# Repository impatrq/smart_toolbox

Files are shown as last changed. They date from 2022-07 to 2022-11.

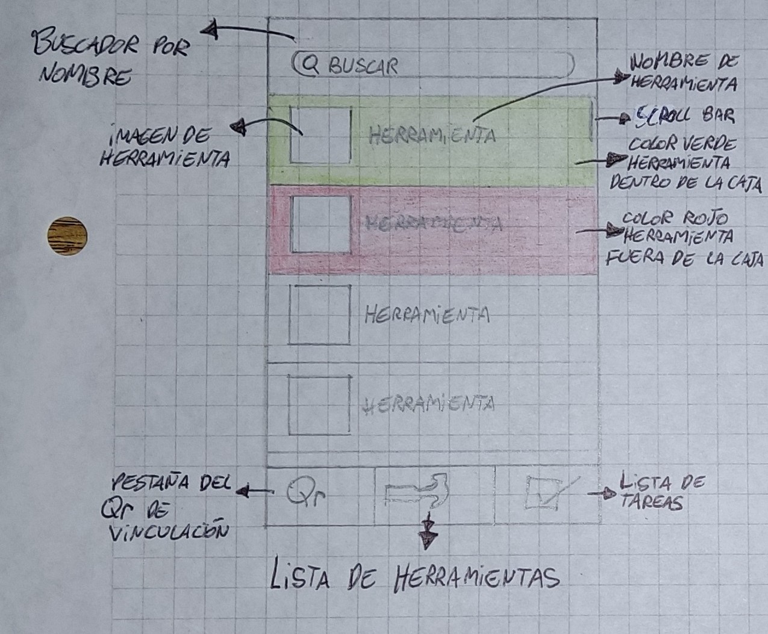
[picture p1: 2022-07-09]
documentacion/diseño-aplicacion-movil/IMG_20220708_201354_3.jpg

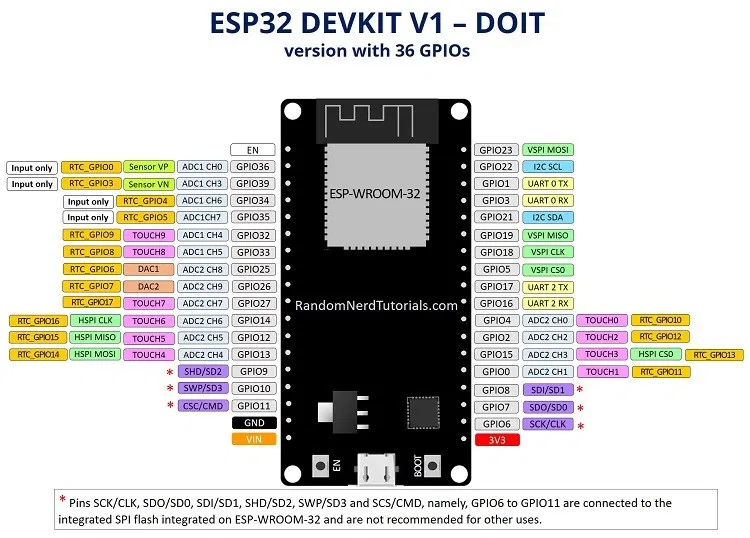
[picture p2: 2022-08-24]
datasheets/ESP32-Pinout.webp

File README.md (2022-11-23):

<div align="center">

# [Smart Toolbox](https://smart-toolbox.vercel.app/)



&nbsp;

| Página web | Email | Instagram |
|---|---|---|
|[smart-toolbox.vercel.app](https://smart-toolbox.vercel.app/)|smart.toolbox@proton.me|[@smart.toolbox.2022](https://www.instagram.com/smart.toolbox.2022)|

&nbsp;

</div>

## ¿Qué es Smart Toolbox?

Smart Toolbox aborda la problemática de los _errores humanos_ en los entornos de trabajo con _herramientas_, que pueden producir _accidentes_ y/o _costos_ adicionales. Con la ayuda de diversas tecnologías creamos un sistema que permite tener un mayor control sobre las herramientas en un taller, reduciendo así el _riesgo de un siniestro_.

## ¿De dónde surgió la idea?

Este proyecto surgió como una variación de otro llamado _Tool Finder_. La principal función de este era la de encontrar, mediante un localizador, las herramientas de trabajo en el taller. A medida que ibamos progresando en el Tool Finder, se fueron descartando y transformando ideas, pero el objetivo de prevenir accidentes nunca cambió. Así surgió _Smart Toolbox_.

## ¿Cómo funciona?

Durante la jornada de trabajo, el operario _dispondrá de todas las tareas a realizar en el día en la aplicación móvil_. Estas serán cargadas a través de una página web.
Después de terminar la jornada de trabajo, el operario deberá guardar todas las herramientas en la caja y, de este modo, evitar el extravío de éstas. En el caso contrario, al cerrarse alguno de los cajones, el sistema _detectará que faltan herramientas_, avisándole de esto mediante un sonido. Los utensilios faltantes se podrán _visualizar en una aplicacion móvil_ vinculada a la caja y en una _interfaz gráfica_.

## Tecnologías utilizadas

### Aplicación móvil

- Ionic con React
- Typescript
- Bootstrap

### Interfaz gráfica

- Electron
- React
- Typescript
- Bootstrap

### Esquemáticos

- KiCad

### Página web

- Next.js
- Typescript
- TailwindCSS
- Bootstrap

### Base de datos

- Firebase Realtime Database

### Microcontrolador

- uPython

### Planos

- AutoCAD

## ¿Quiénes somos?

Somos un grupo de alumnos de E.E.S.T. N°7 "Taller Regional Quilmes" (IMPA).

### Esquivel, Agustín

--> 📧 esquivel.agustin04@gmail.com

### Herrera, Lucas

--> 📧 lucassherreraa2003@gmail.com

### Mariani, Ramiro

--> 📧 ramiromariani99@gmail.com

### Martínez Joaquín

--> 📧 joaquinosmartinez@gmail.com

### Torres, Federico

--> 📧 federicotorres233@protonmail.com

### Vanore, Miqueas

--> 📧 vnmiqueas@gmail.com

<div align="center">



</div>

## Logros

<div align="center">

### 🥇 Primer puesto en Prototipos II 🥇



</div>

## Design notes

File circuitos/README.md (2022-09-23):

# Circuitos
Esta carpeta contiene los archivos de los esquemáticos y las placas de circuito impreso.

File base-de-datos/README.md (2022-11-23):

# Base de datos
Esta carpeta contiene el esquema noSQL que debe ser importado en una base de datos Realtime Database en Firebase y un ejemplo.

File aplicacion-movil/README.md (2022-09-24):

# Aplicación móvil
Esta carpeta contiene el código fuente de la aplicación que le permite al trabajador tener control sobre las herramientas de una caja y de sus tareas a realizar en el día.

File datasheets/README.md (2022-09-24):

# Datasheets
Esta carpeta contiene las hojas de datos de los componentes de Smart Toolbox.

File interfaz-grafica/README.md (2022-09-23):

# Interfaz gráfica
Esta carpeta contiene el código fuente de la aplicación que le permite al encargado del sector tener control total sobre las cajas y sus operarios

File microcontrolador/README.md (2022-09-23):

# Microcontrolador
Esta carpeta contiene el código fuente del microcontrolador dentro de cada caja, que envía infromación sobre su estado y sus herramientas faltantes.

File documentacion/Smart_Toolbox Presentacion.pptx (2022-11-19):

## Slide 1

Integrantes:

- Esquivel, Agustín Lautaro
- Herrera, Lucas Leandro
- Martínez, Joaquín Sebastián
- Mariani, Ramiro Uriel
- Torres, Federico Iván
- Vanore, Miqueas Juan Bautista

## Smart Toolbox

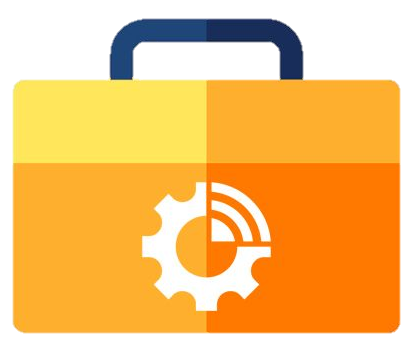
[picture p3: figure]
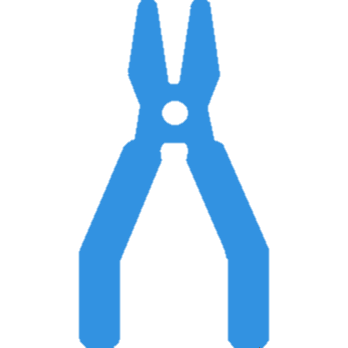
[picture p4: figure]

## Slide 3

¿Cómo funciona?

En la aplicación móvil se mostrarán dichas herramientas.

En la interfaz gráfica se pueden visualizar y administrar cada Smart Toolbox.

Si hay herramientas faltantes, suena una alarma al cerrar todos los cajones.

- Mediante un complejo sistema, advierte al operario si hay alguna herramienta faltante.

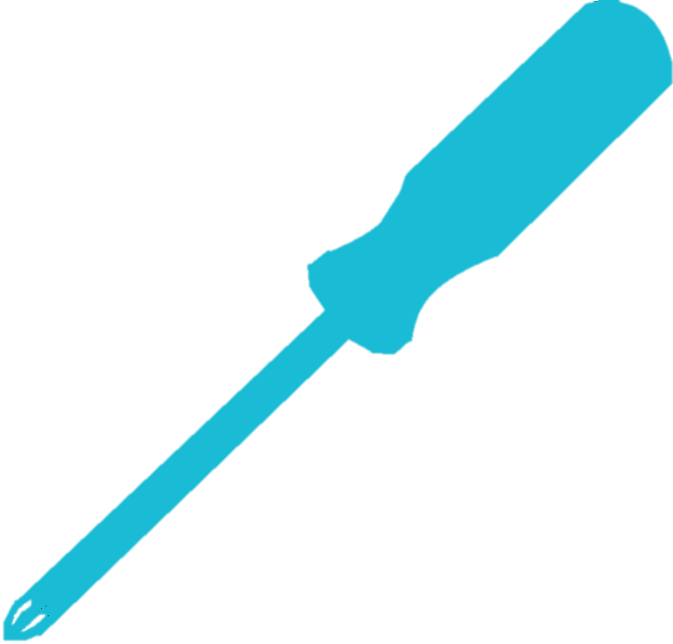
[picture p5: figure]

## El microcontrolador

Envía el estado de cada herramienta a la base de datos

## Cada herramienta:

🔨

- Está asociada a un sensor (para saber si se encuentra, o no, en su lugar)

- Está cargada en una base de datos.

## Los contactos magnéticos

Detectan si los cajones están abiertos o cerrados

## ¿A quién está orientada?

- Empresas
- Talleres mecánicos
- Tripulación y pasajeros del avión
- Operarios especializados en Aeronáutica (MMA) y Aviónica (MERA)

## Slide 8

🔨

¡Grandes beneficios!

Previene pérdidas de dinero millonarias.

Mayor seguridad para la tripulación y pasajeros.

La eficiencia del operario es mejorada.

Se reduce el riesgo de accidentes por olvido de herramientas.

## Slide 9

Cada operario tiene su Smart Toolbox y tiene que registrarse al comienzo del día

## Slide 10

Aplicación móvil

- Permite vincular el usuario con la Smart Toolbox mediante un QR.

- Muestra las tareas a realizar en el día.

- Muestra las herramientas faltantes de la caja.

- Permite vincular el usuario con la Smart Toolbox mediante un QR.

- Muestra las herramientas faltantes de la caja.

- Muestra las tareas a realizar en el día.

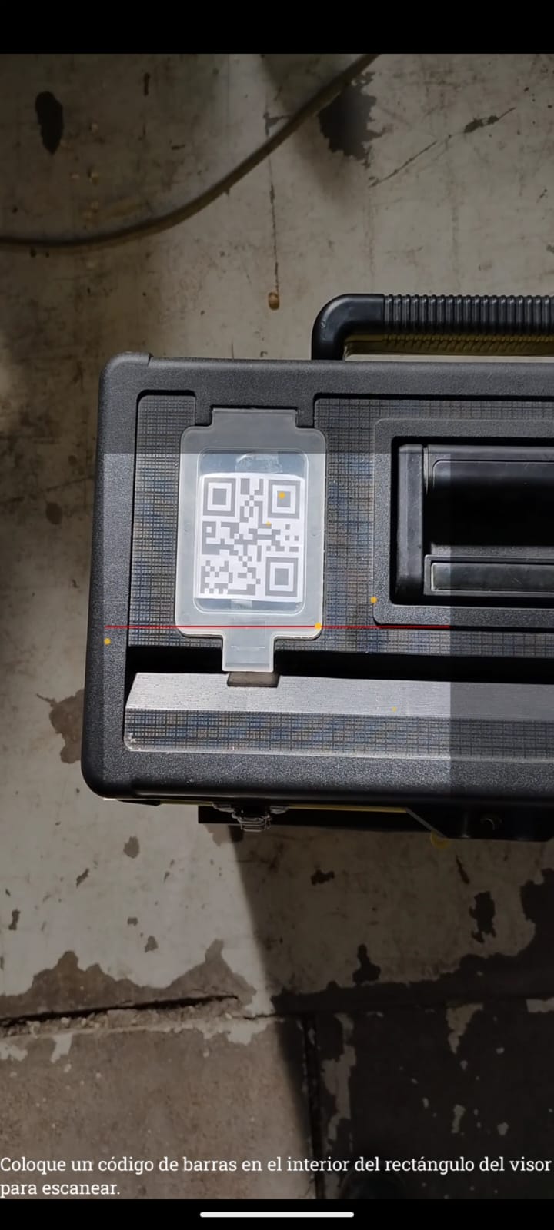
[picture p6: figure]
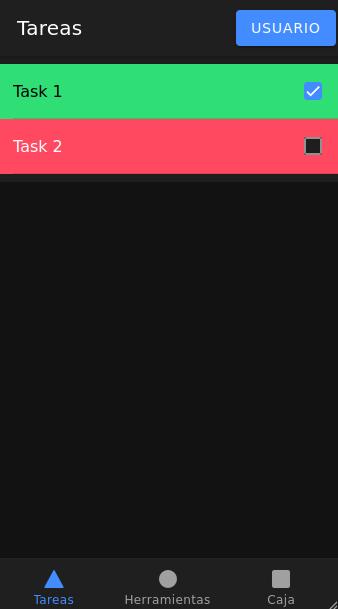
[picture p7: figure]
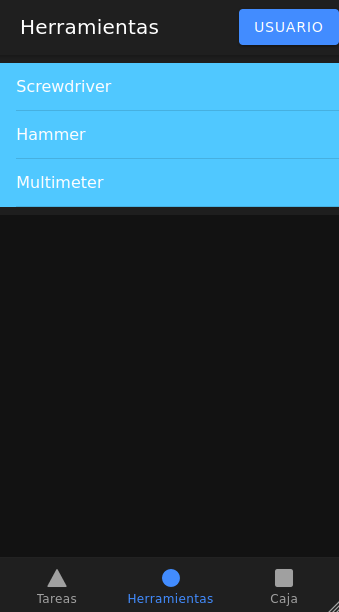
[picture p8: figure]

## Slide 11

Interfaz gráfica

Es una aplicación de escritorio, donde el encargado puede:

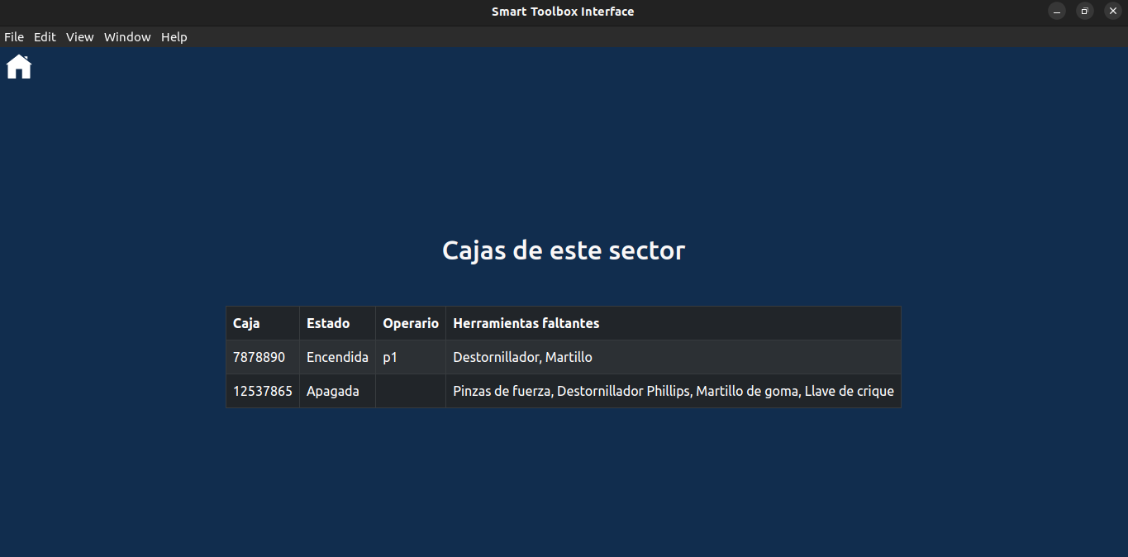
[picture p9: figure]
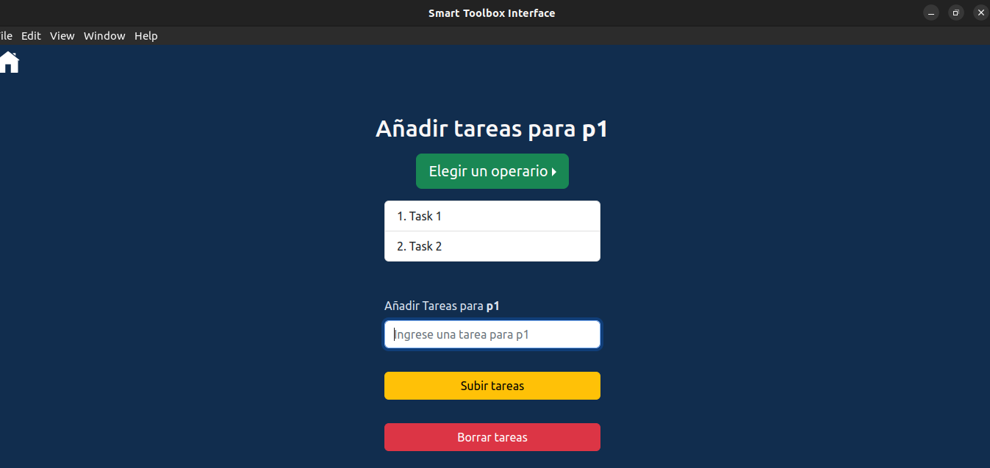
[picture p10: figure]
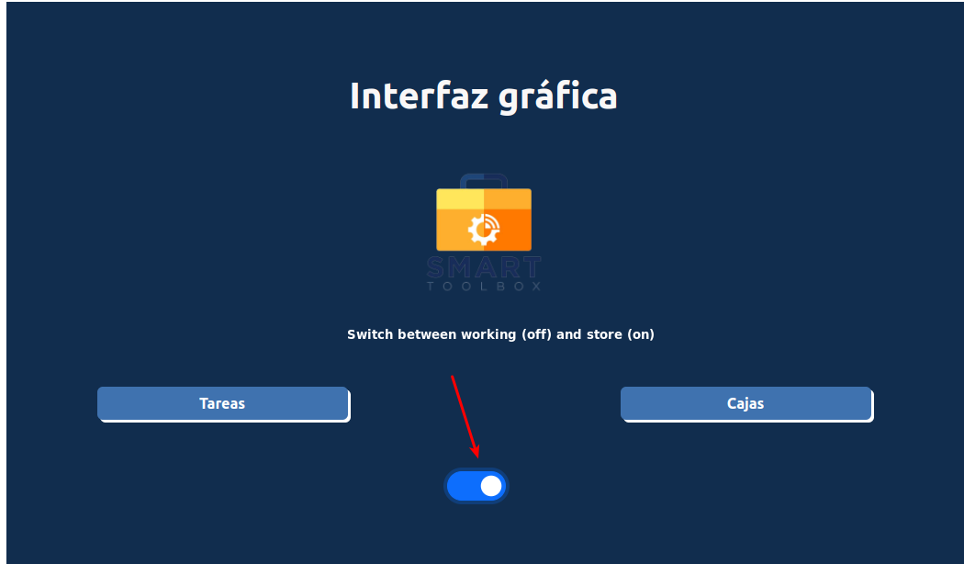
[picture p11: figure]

Ver la información sobre cada Smart Toolbox y a quién está vinculada.

Cargar, en la base de datos, las tareas para hacer en el día por cada operario.

Ver si hay herramientas faltantes.

Determinar el horario de regreso de las Smart Toolbox.

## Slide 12

Smart
Toolbox

Seguridad, Orden y Eficiencia

## Visitanos en:

smart-toolbox.tk

Seguinos en Instagram

@smart.toolbox.2022

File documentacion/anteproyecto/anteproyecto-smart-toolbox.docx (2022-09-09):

Smart Toolbox

Presentación de anteproyecto

Título del proyecto:

El nombre “Smart Toolbox”, es fácil de recordar ya que permite representar de manera rápida en la mente de que trata el proyecto.

Integrantes:

- MARIANI, Ramiro Uriel
- TORRES, Federico Iván
- HERRERA, Lucas Leandro
- ESQUIVEL, Agustín Lautaro
- VANORE, Miqueas Juan Bautista
- MARTÍNEZ, Joaquín Sebastián

Objetivo del proyecto:

Diseñar y construir un sistema que pueda ser integrado a una caja de herramientas aeronáuticas y que indique al usuario las herramientas faltantes o en uso y la calibración vigente en las que corresponda evitando que la caja se pueda cerrar en caso que falte alguna de la dotación a fin de evitar que las mismas se olviden en partes críticas de una aeronave.

Utilidades de el proyecto:

Este proyecto se basa en una solución que pretende reducir la cantidad de accidentes causados por factores humanos en áreas donde se utilicen herramientas, especialmente en áreas aeronáuticas.

Este sistema no solo evita que un trabajador descuidado o cansado pueda cometer el error de dejar herramientas en lugares peligrosos o que estas se extravíen, sino que también permite tener un registro de los trabajadores que utilizaron la caja anteriormente.

Este proyecto está destinado a aquellas empresas que deseen disminuir el número de accidentes, mejorar la organización y tener un registro de la utilización de las herramientas de trabajo. Podrá ser utilizado en cualquier ámbito en el que se requiera el uso de una caja de herramientas, sin embargo está orientado al espacio aeronáutico. En el pasado se han producido accidentes debido a que herramientas se han dejado en lugares peligrosos tales como una turbina. Además el extravío de herramientas es común cuando se trabaja diariamente con éstas. Nuestro proyecto pretende resolver estos inconvenientes.

Reducir el factor humano en los accidentes es vital para cualquier empresa y para cada individuo trabajador, ya que permite evitar futuros problemas, ahorrar tiempo y reducir costos.

Descripción del funcionamiento:

Este sistema, que se basa en una caja de herramientas inteligente, no permite que la misma se cierre si no se encuentran todas las herramientas en ella y hasta que el trabajador revise que después de realizar todas las tareas asignadas no se hayan dejado elementos en el espacio de trabajo, además de proporcionarle una alerta del vencimiento de calibración de las herramientas, si es que estas lo necesiten. Su funcionamiento es el siguiente:

El trabajador que requiera utilizar la caja tendrá a su disposición su tarjeta magnética para abrirla (esto se subirá a la base de datos externa a la parte de historia). Ahora la caja se trabará si ocurren dos sucesos: la caja se cierra por el usuario (no se utiliza ninguna herramienta) o se retiran una o más herramientas. Esto último agregará a la pantalla la herramienta que falta en la sección herramientas. Las secciones del software se pueden visualizar con botones que estarán montados en la caja inteligente. El usuario trabajará normalmente hasta que desee terminar el trabajo. Entonces la caja dispondrá de mecanismos que impedirán que el trabajador pueda cerrar la caja, en caso que todas la herramientas no estén en su respectivo lugar; y si el trabajador no ha marcado como revisadas todas las tareas realizadas anteriormente (en la sección tareas) tocando la pantalla táctil; ésto para verificar que no ha dejado ningún elemento en el espacio de trabajo. Por último, se le pedirá al trabajador que coloque su tarjeta de identificación para firmar que fue este quien cerró la caja en esta instancia. Esto se subirá a una base de datos externa para tener un historial de la caja.

Adicionalmente, la caja mostrará el vencimiento de calibración de las herramientas que lo requieran, en la sección calibración, tales como un torquímetro o un multímetro; Además el sector del pañol podrá tener un registro de los movimientos de las herramientas y usuarios que utilizan la caja mediante una página web.

Opcionalmente, proponemos crear un manual de usuario que permita darle una fácil guía al trabajador que utiliza esta caja inteligente por primera vez.

Funcionamiento de la parte de detección de herramientas: Cada ranura tendrá en los bordes aluminio con cinta aislante con un pequeño espacio en el que el metal será visible. Esto hará que cuando la herramienta no esté en su lugar la goma eva se comprima y el espacio conductor dejará pasar la corriente enviando al multiplexor un 1 en el canal respectivo de la herramienta.

Análisis de factibilidad:

Conocimientos: Los integrantes de este proyecto no poseen todos los conocimientos necesarios para realizar el proyecto. Sin embargo, sí poseen los conocimientos básicos para adquirirlos. Ciertos alumnos tienen mayor conocimiento en electrónica, otros mayor conocimiento de programación y otros mayor conocimiento en circuitos eléctricos. Pese a estas diferencias, todos los integrantes se complementarán en las tareas que se deberán realizar para llevar a cabo la realización del proyecto.

Disponibilidad de componentes: Hemos verificado que todos los componentes están disponibles en el mercado online.

Recursos: Todos los integrantes del proyecto poseen una computadora. Sin embargo, son 2 los que poseen maquinaria y elementos para soldar circuitos, hacer placas etc. en sus hogares.

Proveedores: Pretendemos comprar los componentes vía online y en locales especializados en electrónica.

Estudiante Torres Federico:

Se encargará de la base de datos y las páginas web; y sus interacciones con el microcontrolador (backend).

Estudiante Mariani Ramiro:

Trabajará junto con el alumno anterior en la base de datos, en la construcción de la caja y el diseño del software del display.

Estudiante Herrera Lucas:

Trabajará en los planos y el PCB, la electrónica del sistema (relés) y los circuitos

Estudiante Esquivel Agustín

Trabajará en la electrónica del sistema (multiplexor). Conexiones de circuitos y placas.

Estudiante Joaquín Martínez

Trabajará en los planos y el PCB, el software del display y la optimización de la batería

Estudiante Vanore Miqueas

Trabajará en el diseño del display, construcción de la caja y manual de usuario.

Costo del proyecto:

Componente | Precio en USD | Disponible
Esp32 | 5 USD | Si
Caja de herramientas | 89 USD | Si
Arduino Uno | 10 USD | Si
Pantalla táctil 2.5” | 18 USD | Si
Lector RFID | 3.5 USD | Si
Pulsador push x3 | 1 USD x3 | Si
Relé | 3 USD | Si
Cables | 3 USD | Si
Placa de aluminio | 2 USD | Si
Goma eva | 4 USD | Si
Herramientas | - | Si
Batería 6V | 6 USD | Si
Multiplexor x2 | 1.5 USD x2 | Si
Cerradura eléctrica x2 | 6 USD x2 | Si

Costo total del proyecto:

- 179.5$USD (con caja de herramientas)
- 90.5$USD (sin caja de herramientas)

Referencias:

https://www.xataka.com/seleccion/que-modelo-raspberry-pi-comprar-repaso-a-principales-placas-proyectos-habituales-para-dar-mejor

https://www.mercadolibre.com.ar/

https://tutuerca.com/blog/tipos-de-cajas-de-herramientas/

https://clongeek.com/3-maneras-de-alimentar-raspberry-pi/

https://articulo.mercadolibre.com.ar/MLA-921892605-boton-pulsador-arcade-30mm-push-varios-colores-_JM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

https://articulo.mercadolibre.com.ar/MLA-621827216-cerradura-electrica-luber-1500-doble-bobina-destrabapestillo-_JM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

Análisis de costo/beneficio:

El proyecto sería financiable ya que permitiría un mayor control sobre los trabajadores y mayor seguridad ante posibles accidentes. Una empresa aeronáutica o cualquiera en la que se utilicen herramientas les sería muy útil tener seguridad adicional. Aunque a simple vista parece una inversión un poco costosa, la posibilidad de averiarse maquinaria o estructuras aún más costosas lo hace una buena opción.

Diagrama en bloques del prototipo:

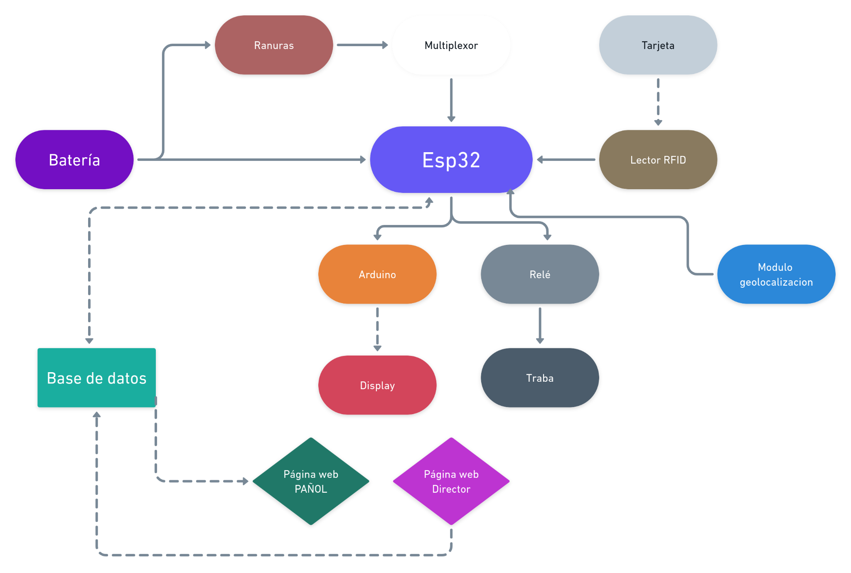
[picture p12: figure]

- Batería: proporciona energía al microcontrolador y a los sensores.
- Arduino: sobre este estará montado el display
- Display: tendrá tres secciones que mostrarán las herramientas que faltan, el vencimiento de calibración y las tareas a realizar
- Esp32: es la unidad central que controlará todo el sistema
- Ranuras y multiplexor: detectarán cuál herramienta está y cuál no
- RFID: permitirán identificar al usuario que está usando el sistema
- Relé y traba: permiten bloquear la caja
- Base de datos: Guardará el historial de usuarios, las tareas a realizar, el vencimiento de caducación de las herramientas
- Página web pañol: permitirá visualizar las herramientas y usuarios utilizados en el momento
- Página web director: permitirá subir un archivo con las tareas (JSON)

Diagrama de tiempo de desarrollo:

Tareas a realizar | 1 | 2 | 3 | 4 | 5 | 6 | 7 | 8 | 9 | 10 | 11 | 12 | 13 | 14 | 15 | 16 | 17 | 18 | 19 | 20 | 21 | 22 | 23 | 24 | 25
Ideas
Anteproyecto
Aplicaciones y recursos
Circuitos esquemas
Base de datos
Programación interfaz gráfica display
Goma eva siluetas de herramientas
Aluminio y cinta aislante
Conexiones eléctricas
Programación módulos
Páginas web
Interacciones con base de datos
Optimización de la batería
Manual de usuario y complementos

Escuela de Educación Técnica Nº7 Taller Regional Quilmes Prácticas Profesionalizantes: Especialidad Aviónica

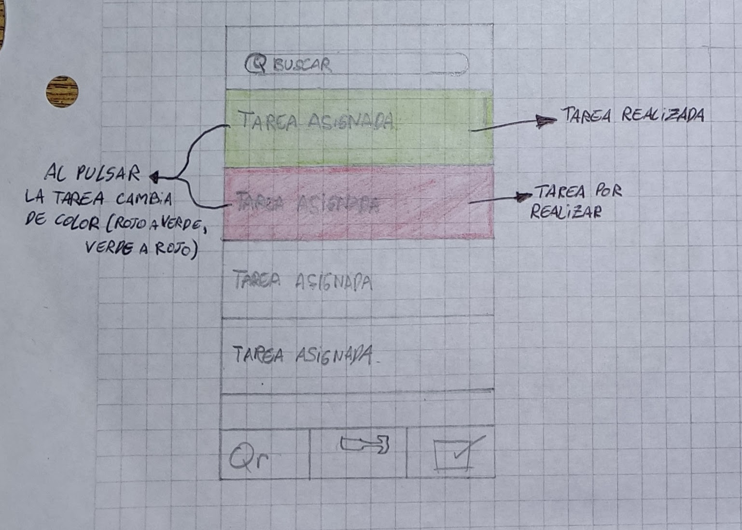
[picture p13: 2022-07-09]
documentacion/diseño-aplicacion-movil/lista de tareas.jpg

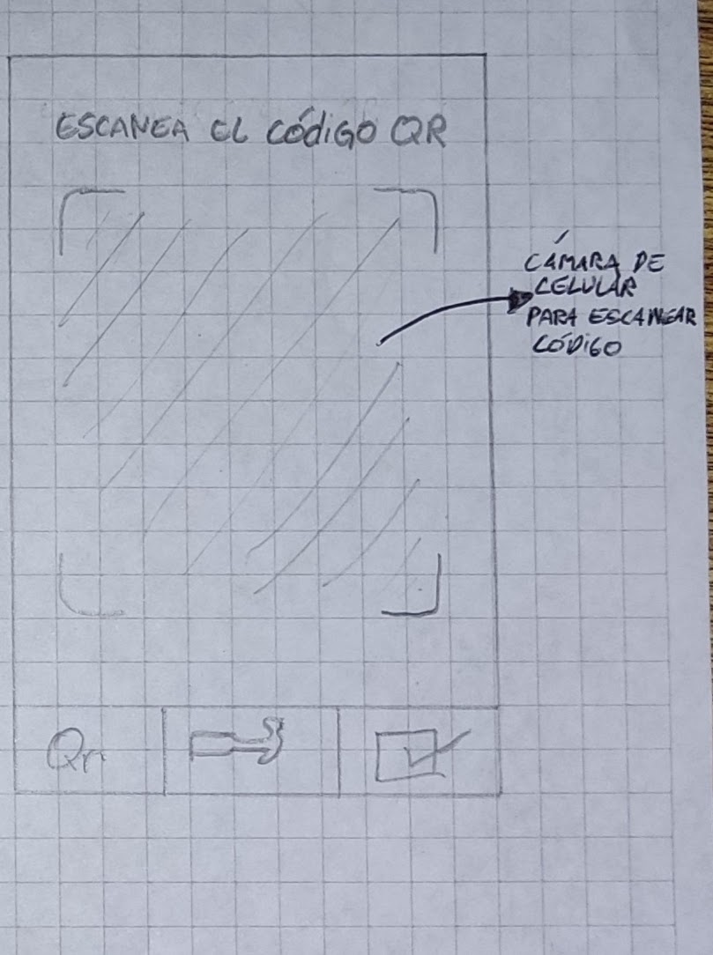
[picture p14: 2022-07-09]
documentacion/diseño-aplicacion-movil/lector qr.jpg

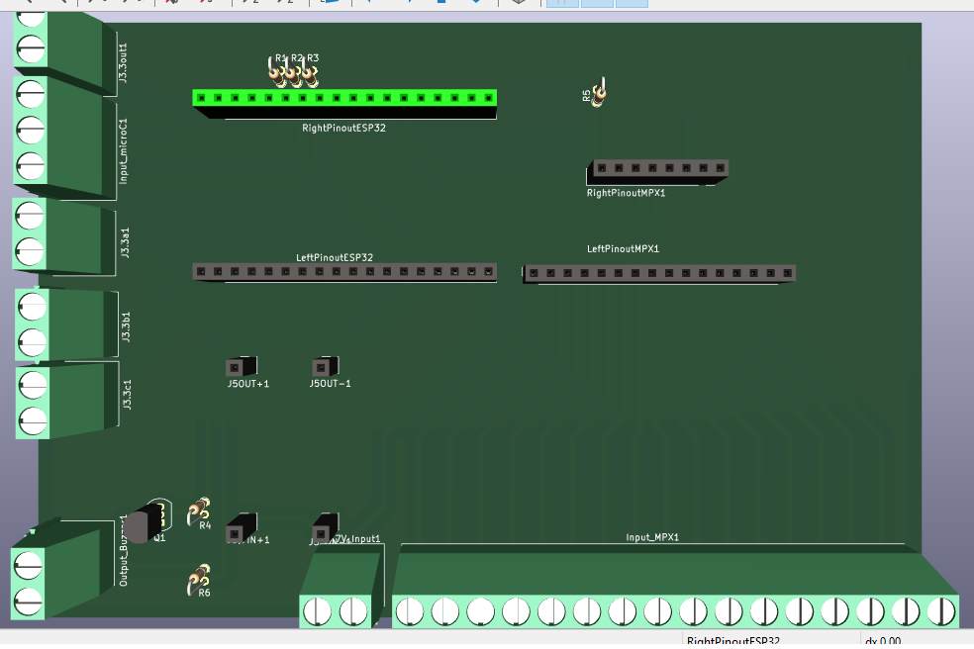
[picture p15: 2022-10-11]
circuitos/cIrcuito-impreso/imagenes/PCB-vista-superior.png

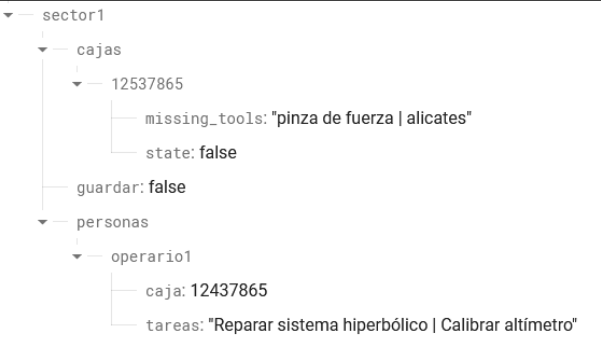
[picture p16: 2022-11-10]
base-de-datos/Ejemplo base de datos.png

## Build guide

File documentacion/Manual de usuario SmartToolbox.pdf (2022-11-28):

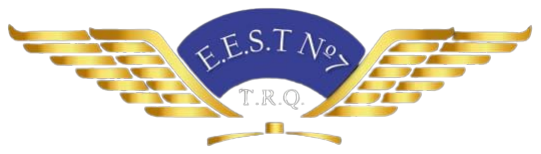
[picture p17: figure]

GUÍA DE USO Y ASISTENCIA AL OPERARIO

# MANUAL DE USUARIO

# Smart Toolbox

Dirección: Av. Otamendi,
B1878 Quilmes, Provincia de Buenos Aires

Teléfono: 011 4254-1512

smart-toolbox.vercel.app

# Contenido

## II. Guía de uso de aplicación móvil | X

1. Ingreso al sistema | X
1.1 Sección de Tareas | X
1.2 Sección de Herramientas | X
1.3 Sección de Caja | X

## III. Guía de uso de interfaz gráfica | X

1. Guía de instalación | X
| 1.1 Botón de guardado | X 1.2 Sección de Tareas | X 1.3 Sección de Caja | X
MANUAL DE USUARIO | Guía de uso de aplicación móvil – 2
MANUAL DE USUARIO | Introducción – 1
MANUAL DE USUARIO | Guía de uso de interfaz gráfica – 2

## I. Introducción

### 1. Objetivo

Smart Toolbox es un sistema que brinda un nuevo sistema de orden y seguimiento de herramientas en el espacio de trabajo, para así prevenir accidentes o pérdidas de dinero en bienes laborales. Poseerá una lista de actividades que le brindará al trabajador una mayor comodidad, además de reducir el margen de error por un olvido. Adicionalmente, estará disponible una interfaz gráfica que tendrá el control total del sistema.

2. Requerimientos.
- Conexión a internet.
- Espacio de 9 megabytes en el celular (aplicación móvil).
- Espacio de 100 megabytes en la computadora (interfaz gráfica).
- Windows 10+ o una distribución de Linux.
- Versión de Android 8 en adelante.
- Se necesita un espacio de aproximadamente 72 x 49 x 27,5 cm para usar libremente la caja.
- Superficie que soporte aproximadamente 30kg (peso de la caja).
3. Precauciones.
- Evitar el contacto con fuego o superficies inflamables.
- Utilizar la correcta indumentaria de trabajo para evitar posibles lesiones por herramientas, etc.
- Precaución por posible peligro eléctrico durante su carga.

MANUAL DE USUARIO | Introducción - 1

## II. Guía de uso de aplicación móvil

El presente Manual está organizado de acuerdo a la secuencia de ingreso a las pantallas del sistema de la siguiente manera:
1. Ingreso al sistema.
1.1 | Sección de Tareas
1.2 | Sección de Herramientas
1.3 | Sección de Caja

### 1. Ingreso al sistema

Al iniciar la aplicación se le presentarán varias secciones, y el trabajador deberá ingresar su usuario para acceder a las herramientas y tareas previamente ingresadas en la base de datos.
Para eso, este mismo debe digitar el usuario apretando el siguiente botón

En esta interfaz debe ingresarse el Nombre y Apellido, y presionar sobre el botón una vez completado. De esta forma se logra ingresar en el sistema y aparecerán las tareas disponibles y herramientas desde la base de datos.

MANUAL DE USUARIO Guía de uso de aplicación móvil – 2

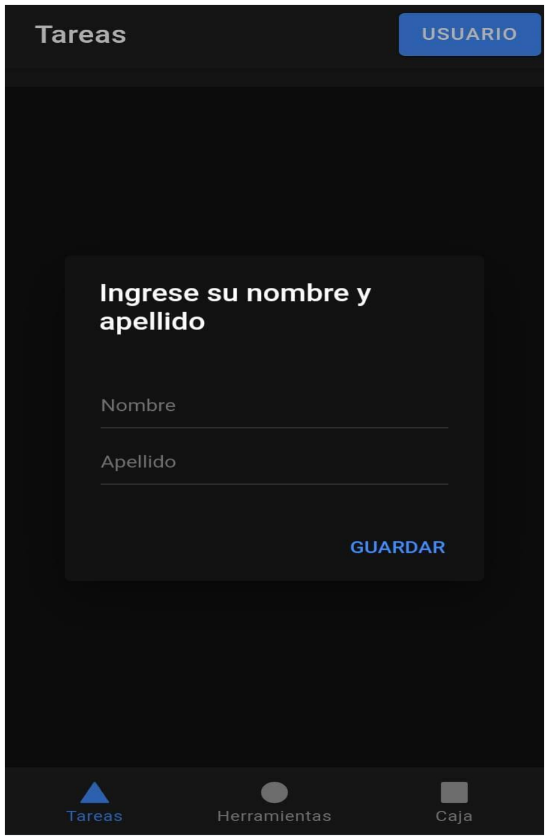
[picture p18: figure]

### 1.1 Sección de Tareas

En esta sección, ubicada en la parte inferior izquierda de la aplicación, se le presentaran al operario las tareas a realizar, designadas por un superior. Las tareas estarán coloreadas en rojo cuando no estén realizadas. Una vez terminada se debe pulsar sobre la tarea para ser coloreada en verde que este mismo significa que la tarea está realizada.

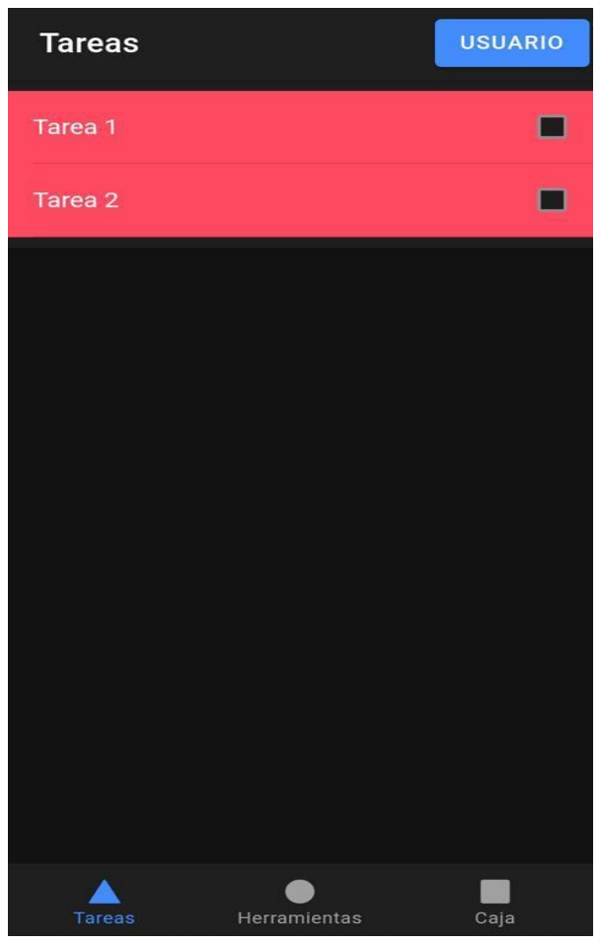
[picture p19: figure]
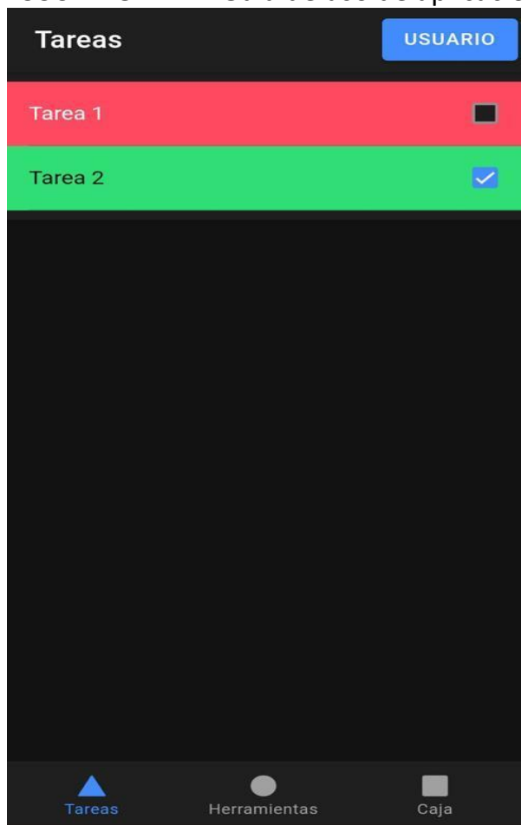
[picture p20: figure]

MANUAL DE USUARIO Guía de uso de aplicación móvil – 3

### 1.2 Sección de Herramientas

Aquí se muestran las herramientas faltantes en la caja vinculada al usuario. Si una herramienta aparece en pantalla, significa que esta misma, no está en la caja, se debe buscar donde se encuentra para devolverla a su respectiva caja si no está siendo usada. Después de esto, el nombre de la herramienta desaparecerá de la pantalla.

MANUAL DE USUARIO Guía de uso de aplicación móvil – 4

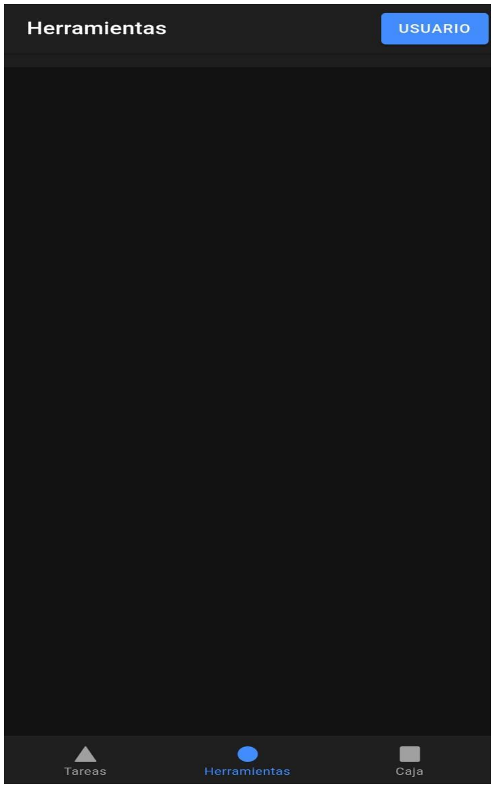
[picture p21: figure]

### 1.3 Sección de Caja

Está sección contiene un botón amarillo en la parte central. Al presionarlo, se abrirá la cámara del móvil y se podrá escanear el código QR en la caja de herramientas a la que se desee vincularse. Luego de haberse escaneado el código QR, aparecerán en la sección de Herramientas los utensilios faltantes. Cabe aclarar que es necesario autenticarse previo al escaneo del código QR.

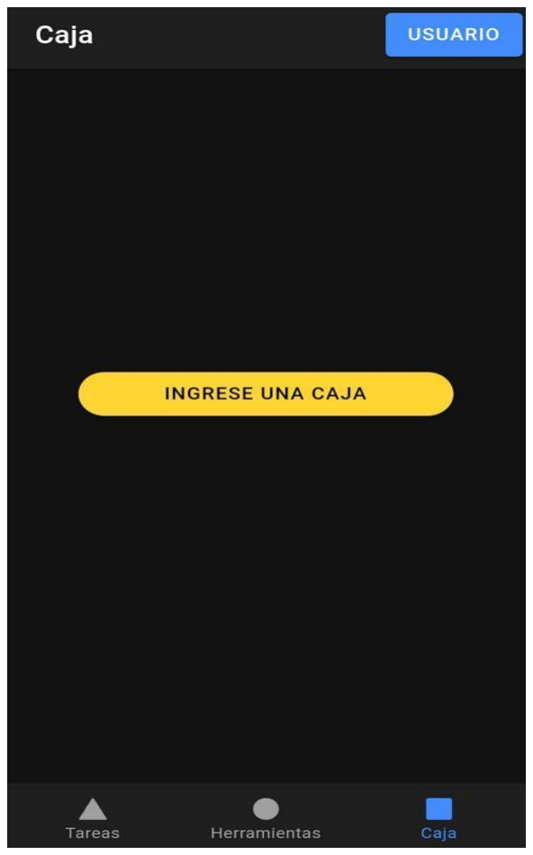
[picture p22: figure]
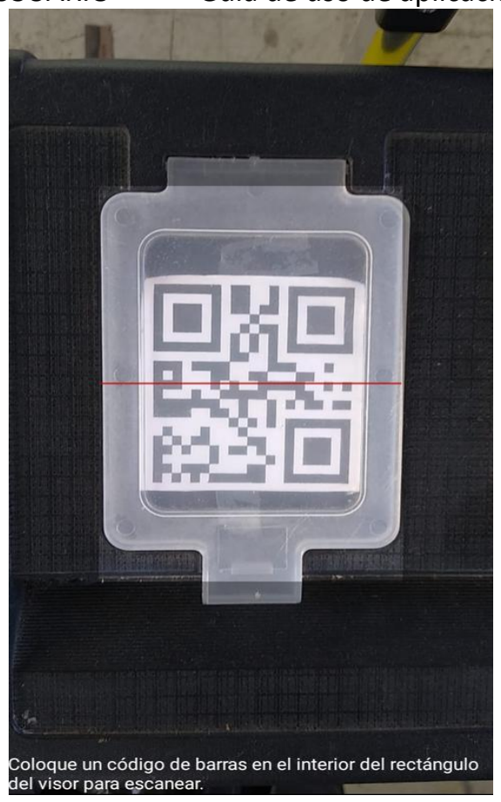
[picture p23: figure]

MANUAL DE USUARIO Guía de uso de aplicación móvil – 5

## III.Guía de uso de interfaz gráfica

Este apartado está organizado de acuerdo a como están presentados en la pantalla la interfaz gráfica de la siguiente manera:
1. Guía de instalación.
1.1 Botón de guardado.
1.2 Sección de Tareas.
1.3 Sección de Caja.

### 1. Guía de instalación

En esta sección se explicará el cómo se debe instalar la interfaz gráfica para su correcto funcionamiento:
Primero se deberá ingresar al GitHub personal de la SmartToolbox, este es el link de donde se obtendrá la posibilidad de descargarlo:

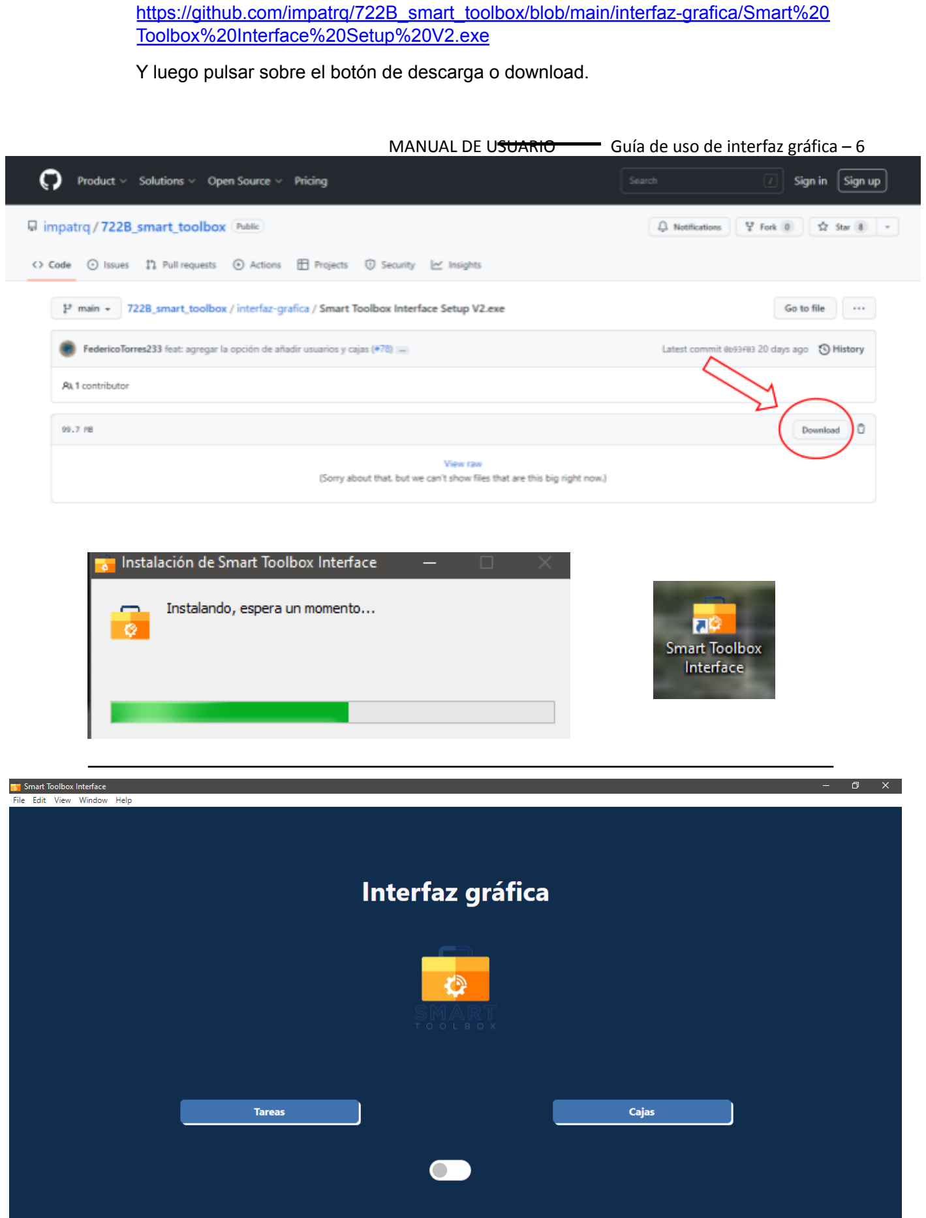
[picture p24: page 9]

https://github.com/impatrq/722B_smart_toolbox/blob/main/interfaz-grafica/Smart%20 Toolbox%20Interface%20Setup%20V2.exe (https://github.com/impatrq/722B_smart_toolbox/blob/main/interfaz-grafica/Smart%20Toolbox%20Interface%20Setup%20V2.exe)
Y luego pulsar sobre el botón de descarga o download.
MANUAL DE USUARIO | Guía de uso de interfaz gráfica – 6

MANUAL DE USUARIO | Guía de uso de interfaz gráfica – 7

### 1.1 Botón de guardado

El botón de guardado indica el momento en que las cajas deben ser devueltas a su depósito. Al pulsar el botón las cajas se activan poniendo en marcha el sistema SmartToolbox.

### 1.2Sección de Tareas

En este apartado es posible elegir el usuario y poder asignarle las tareas a realizar. También, se es capaz de agregar nuevos usuarios y a estos también asignarles sus tareas correspondientes, las cuales deberán pulsar sobre ellas en la aplicación una vez que estén completadas.

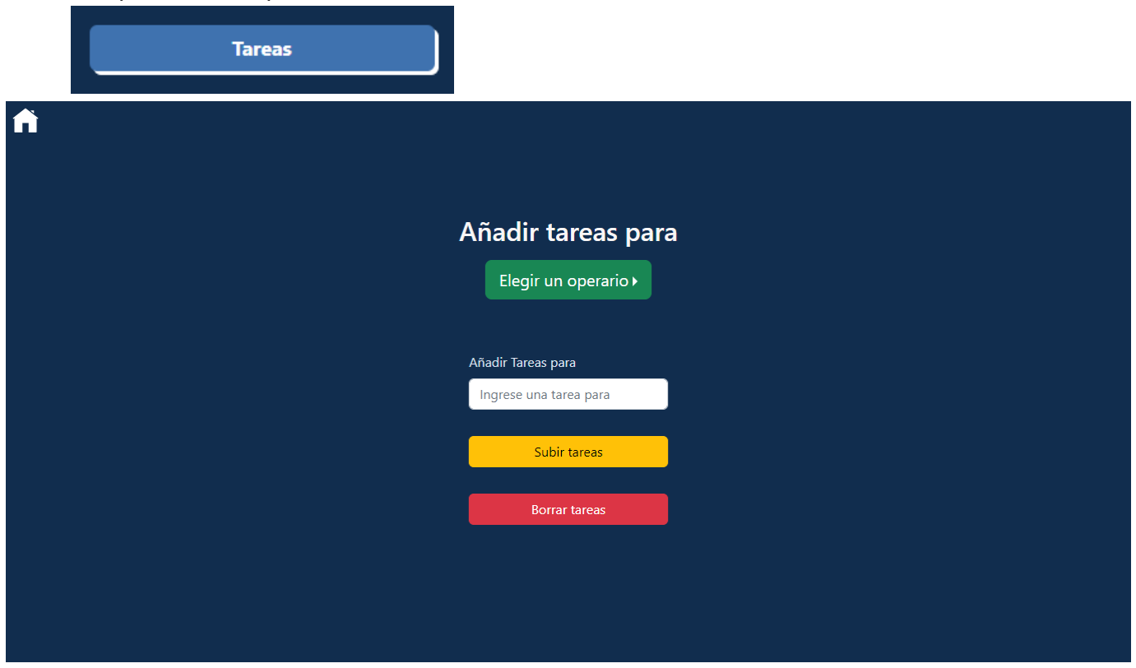
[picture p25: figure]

MANUAL DE USUARIO | Guía de uso de interfaz gráfica – 8

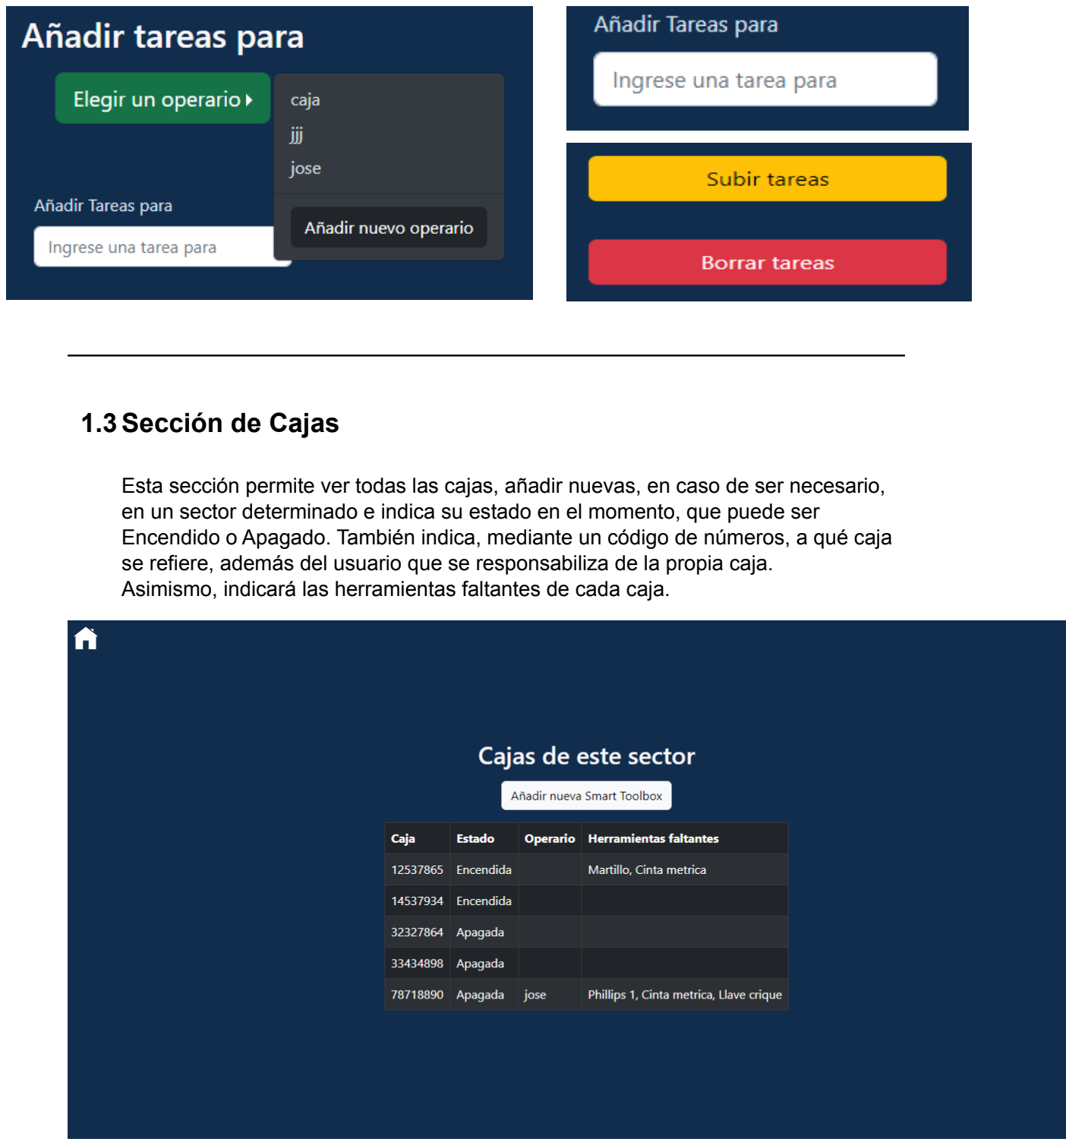
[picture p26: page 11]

### 1.3Sección de Cajas

Esta sección permite ver todas las cajas, añadir nuevas, en caso de ser necesario, en un sector determinado e indica su estado en el momento, que puede ser Encendido o Apagado. También indica, mediante un código de números, a qué caja se refiere, además del usuario que se responsabiliza de la propia caja.
Asimismo, indicará las herramientas faltantes de cada caja.

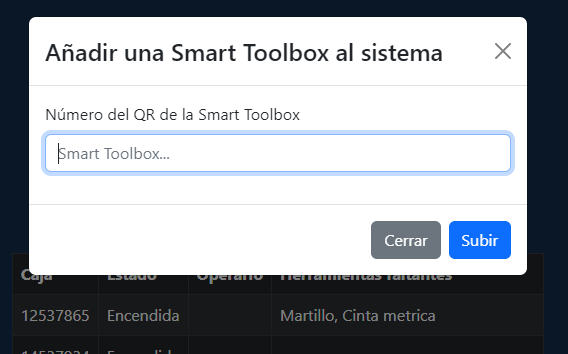
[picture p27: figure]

MANUAL DE USUARIO | Guía de uso de interfaz gráfica – 9

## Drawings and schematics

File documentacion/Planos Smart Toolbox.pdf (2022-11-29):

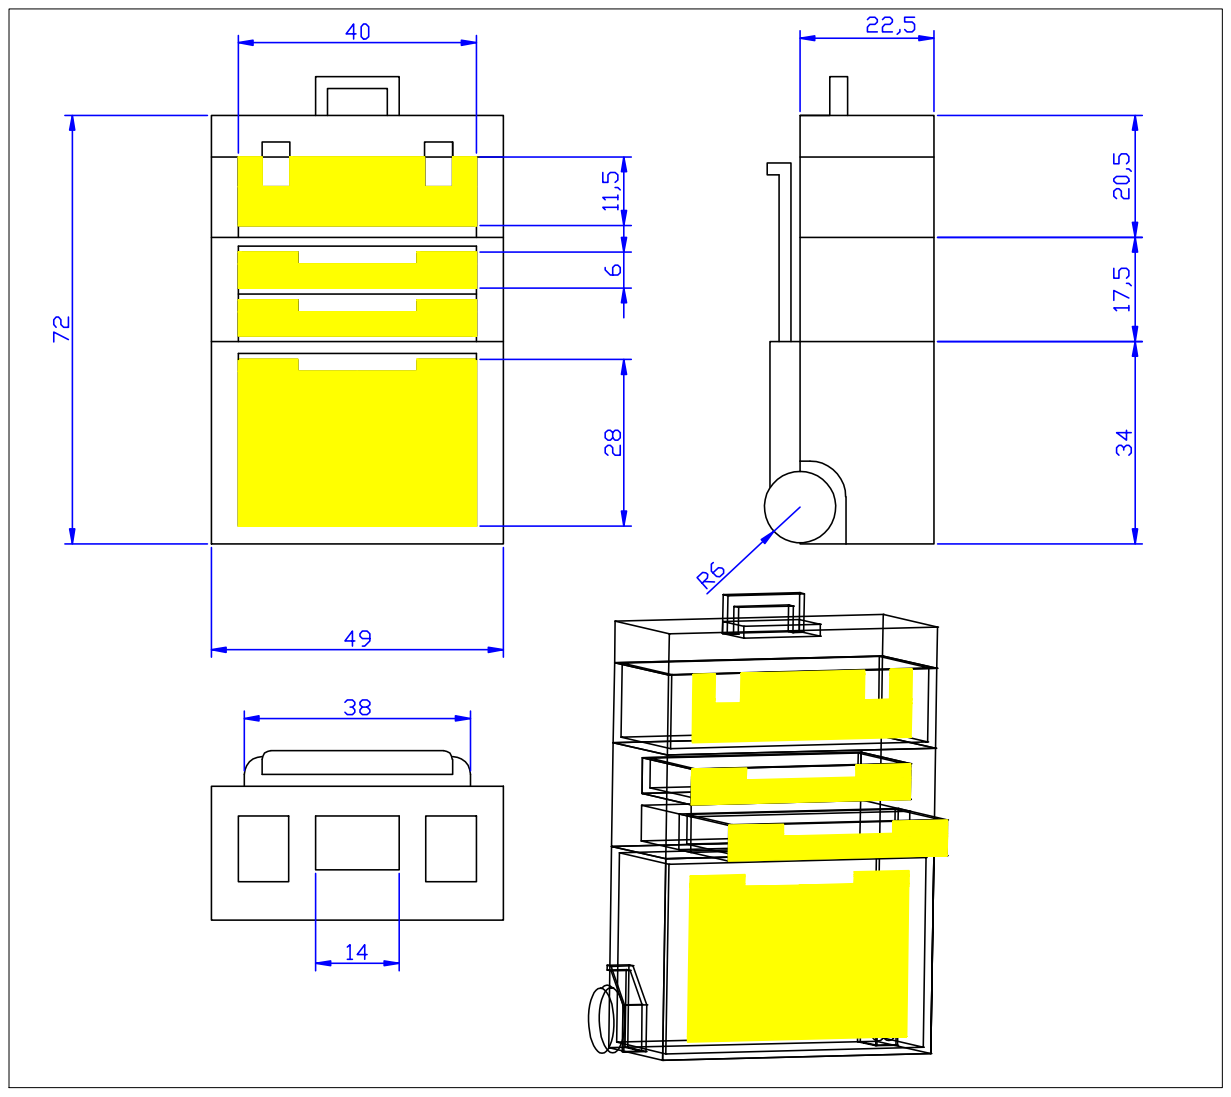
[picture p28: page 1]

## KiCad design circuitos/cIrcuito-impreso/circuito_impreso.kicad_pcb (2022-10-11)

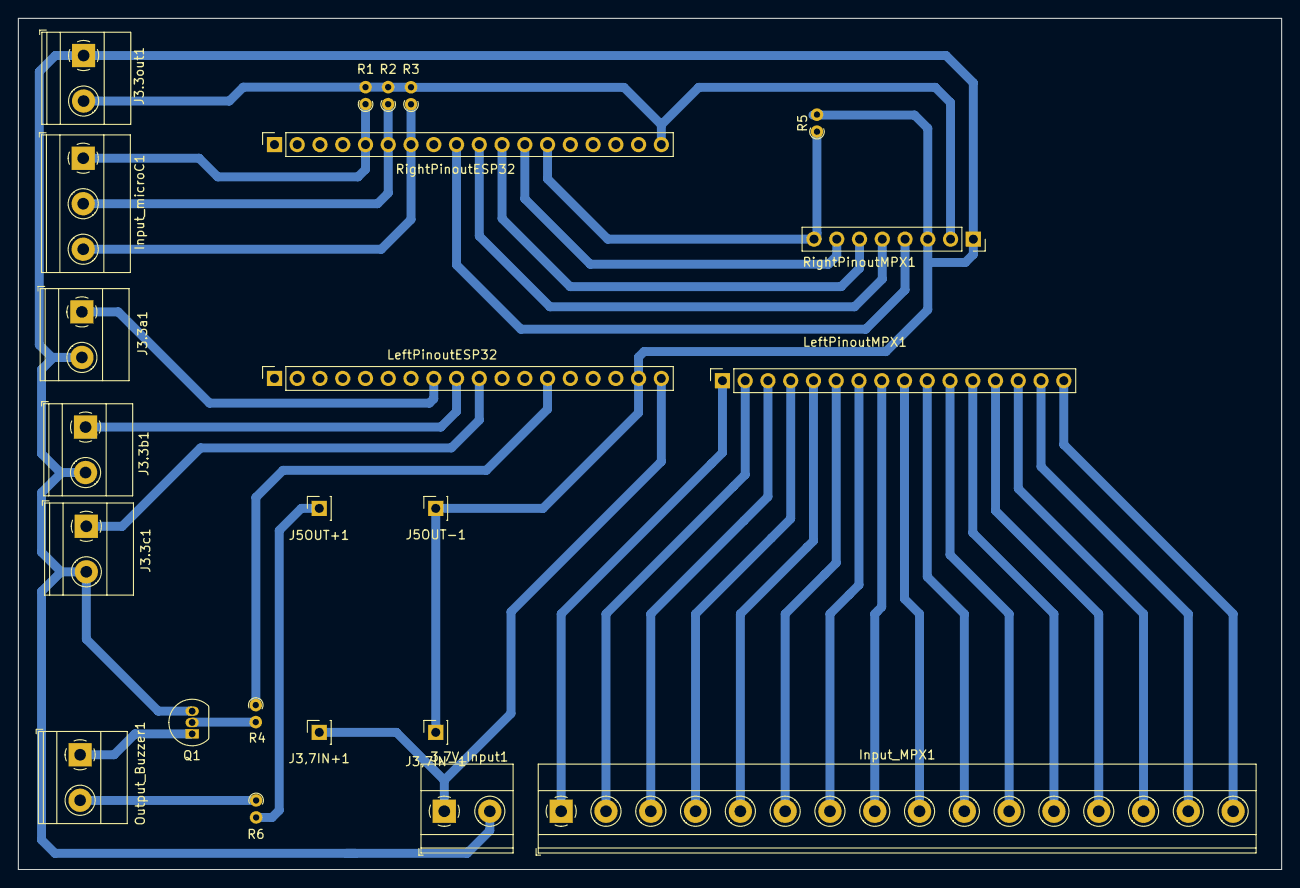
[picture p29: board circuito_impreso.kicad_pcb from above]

Board: 2 copper layers, 141.0 x 95.0 mm, 23 parts (0 on the bottom side), 35 nets.

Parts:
3,7V_Input1: Screw_Terminal_01x02; TerminalBlock_Phoenix_MKDS-1,5-2-5.08_1x02_P5.08mm_Horizont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
Input_MPX1: Screw_Terminal_01x16; TerminalBlock_Phoenix_MKDS-1,5-16_1x16_P5.00mm_Horizontal
Input_microC1: Screw_Terminal_01x03; TerminalBlock_Phoenix_MKDS-1,5-3-5.08_1x03_P5.08mm_Horizont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
J3,7IN+1: Vin+; PinSocket_1x01_P2.54mm_Vertical
J3,7IN-1: Vin-; PinSocket_1x01_P2.54mm_Vertical
J3.3a1, J3.3b1, J3.3c1, J3.3out1: Screw_Terminal_01x02; TerminalBlock_Phoenix_MKDS-1,5-2-5.08_1x02_P5.08mm_Horizont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
J5OUT+1: Vout+; PinSocket_1x01_P2.54mm_Vertical
J5OUT-1: Vout-; PinSocket_1x01_P2.54mm_Vertical
LeftPinoutESP32: Conn_01x18_Female_Left; PinSocket_1x18_P2.54mm_Vertical
LeftPinoutMPX1: Conn_01x16_Female_Left; PinSocket_1x16_P2.54mm_Vertical
Output_Buzzer1: Alarma; TerminalBlock_Phoenix_MKDS-1,5-2-5.08_1x02_P5.08mm_Horizont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
Q1: BC548; TO-92_Inline
R1, R2, R3, R5: 4,7K; R_Axial_DIN0204_L3.6mm_D1.6mm_P1.90mm_Vertical
R4: 470; R_Axial_DIN0204_L3.6mm_D1.6mm_P1.90mm_Vertical
R6: 1K; R_Axial_DIN0204_L3.6mm_D1.6mm_P1.90mm_Vertical
RightPinoutESP32: Conn_01x18_Female_Right; PinSocket_1x18_P2.54mm_Vertical
RightPinoutMPX1: Conn_01x08_Female_Right; PinSocket_1x08_P2.54mm_Vertical

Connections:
3.3V: J3.3out1.2, R1.2, R2.2, R3.2, RightPinoutESP32.18, RightPinoutMPX1.2
3.7V: 3,7V_Input1.1, J3,7IN+1.1, LeftPinoutESP32.18
5V: J5OUT+1.1, R6.2
/C0: Input_MPX1.16, LeftPinoutMPX1.16
/C1: Input_MPX1.15, LeftPinoutMPX1.15
/C2: Input_MPX1.14, LeftPinoutMPX1.14
/C3: Input_MPX1.13, LeftPinoutMPX1.13
/C4: Input_MPX1.12, LeftPinoutMPX1.12
/C5: Input_MPX1.11, LeftPinoutMPX1.11
/C6: Input_MPX1.10, LeftPinoutMPX1.10
/C7: Input_MPX1.9, LeftPinoutMPX1.9
/C8: Input_MPX1.8, LeftPinoutMPX1.8
/C9: Input_MPX1.7, LeftPinoutMPX1.7
/C10: Input_MPX1.6, LeftPinoutMPX1.6
/C11: Input_MPX1.5, LeftPinoutMPX1.5
/C12: Input_MPX1.4, LeftPinoutMPX1.4
/C13: Input_MPX1.3, LeftPinoutMPX1.3
/C14: Input_MPX1.2, LeftPinoutMPX1.2
/C15: Input_MPX1.1, LeftPinoutMPX1.1
GND: 3,7V_Input1.2, J3,7IN-1.1, J3.3a1.2, J3.3b1.2, J3.3c1.2, J3.3out1.1, J5OUT-1.1, LeftPinoutESP32.17, Q1.3 (E), R5.2, RightPinoutMPX1.1, RightPinoutMPX1.3
GPIO2: RightPinoutESP32.12, RightPinoutMPX1.7
GPIO4: RightPinoutESP32.11, RightPinoutMPX1.6
GPIO13: LeftPinoutESP32.13, R4.1
GPIO15: R5.1, RightPinoutESP32.13, RightPinoutMPX1.8
GPIO16: RightPinoutESP32.10, RightPinoutMPX1.5
GPIO17: RightPinoutESP32.9, RightPinoutMPX1.4
GPIO18: Input_microC1.3, R3.1, RightPinoutESP32.7
GPIO19: Input_microC1.2, R2.1, RightPinoutESP32.6
GPIO21: Input_microC1.1, R1.1, RightPinoutESP32.5
GPIO25: J3.3a1.1, LeftPinoutESP32.8
GPIO26: J3.3b1.1, LeftPinoutESP32.9
GPIO27: J3.3c1.1, LeftPinoutESP32.10
unnamed: Output_Buzzer1.1, Q1.1 (C)
unnamed: Output_Buzzer1.2, R6.1
unnamed: Q1.2 (B), R4.2

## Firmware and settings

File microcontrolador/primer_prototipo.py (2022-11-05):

# Smart Toolbox Esp32 first main program
#
# Github: https://github.com/impatrq/722B_smart_toolbox
#
# Author: https://github.com/FedericoTorres233

from machine import Pin
import time
import network
import urequests as ureq

# Environmental variables
WIFI_SSID = ""
WIFI_PASSWD = ""
DB_ID = ""

# Workspace
area_trabajo = "sector1"

# DB Url
dbURL = f"https://smart-toolbox-{DB_ID}-default-rtdb.firebaseio.com"

# Toolbox Number
toolbox = "14537934"

# Headers
HTTP_HEADERS = {"Content-Type": "application/json"}

# I/O Ports
s0 = Pin(17, Pin.OUT)
s1 = Pin(16, Pin.OUT)
s2 = Pin(4, Pin.OUT)
s3 = Pin(2, Pin.OUT)
alarm = Pin(13, Pin.OUT)
sig = Pin(15, Pin.IN)
c1 = Pin(19,Pin.IN)
c2 = Pin(18,Pin.IN)
c3 = Pin(21,Pin.IN)

alarm.off()
missing_tools = []

# Tools constructor
class Tools:
    def __init__(self, num, sel, nombre):
        self.num = num
        self.sel = sel
        self.nombre = nombre


# Tool objects
martillo = Tools(0, [0, 0, 0, 0], "Martillo")
fuerza = Tools(1, [0, 0, 0, 1], "Pinza de fuerza")
cutter = Tools(2, [0, 0, 1, 0], "Cutter")
torx = Tools(3, [0, 0, 1, 1], "Llaves torx")
pelacables = Tools(4, [0, 1, 0, 0], "Pelacables")
punta1 = Tools(5, [0, 1, 0, 1], "Pinza de punta 1")
alicates = Tools(6, [0, 1, 1, 0], "Alicates")
punta2 = Tools(7, [0, 1, 1, 1], "Pinza de punta 2")
loro = Tools(8, [1, 0, 0, 0], "Pico de loro")
francesa = Tools(9, [1, 0, 0, 1], "Llave francesa")
frenar = Tools(10, [1, 0, 1, 0], "Pinza de frenar")
phillips1 = Tools(11, [1, 0, 1, 1], "Destornillador Phillips 1")
plano1 = Tools(12, [1, 1, 0, 0], "Destornillador Plano 1")
phillips2 = Tools(13, [1, 1, 0, 1], "Destornillador Phillips 2")
plano2 = Tools(14, [1, 1, 1, 0], "Destornillador Plano 2")
metrica = Tools(15, [1, 1, 1, 1], "Cinta metrica")


# Finds if a tool is in the missing_tools list
def checkDuplicates(tool):
    return tool in missing_tools

def checkContacts():
    if not c1.value() and not c2.value() and not c3.value():
        return True
    else:
        return False

# Connect to the wifi network
def connectWifi():
    wlan = network.WLAN(network.STA_IF)
    wlan.active(True)
    if not wlan.isconnected():
        wlan.connect(WIFI_SSID, WIFI_PASSWD)
        while not wlan.isconnected():
            time.sleep_ms(1000)


# REST API get method
def getReq(param):
    return ureq.get(f"{dbURL}/{area_trabajo}/{param}.json", headers=HTTP_HEADERS).json()


# REST API patch method
def patchReq(param, js):
    return ureq.patch(f"{dbURL}/{area_trabajo}/{param}.json", json=js, headers=HTTP_HEADERS).json()


# This makes the tools iterable
tools = [
    martillo,
    fuerza,
    cutter,
    torx,
    pelacables,
    punta1,
    alicates,
    punta2,
    loro,
    francesa,
    frenar,
    phillips1,
    plano1,
    phillips2,
    plano2,
    metrica,
]

# Connect to the Wifi network
connectWifi()

# Main event loop
while True:

    while not getReq("guardar"):
        patchReq(f"cajas/{toolbox}", {"missing_tools": "", "state": False})
        time.sleep(10)  # Waits until the store signal arrives

    for tool in tools:
        if tool.sel[3] == 1:
            s0.on()
        if tool.sel[2] == 1:
            s1.on()
        if tool.sel[1] == 1:
            s2.on()
        if tool.sel[0] == 1:
            s3.on()

        # ! This delay ensures an effective multiplexer switching

        if not sig.value():
            # * The tool is not in its place
            if not checkDuplicates(tool.nombre):
                missing_tools.append(tool.nombre)
        else:
            # * The tool is in its place
            if checkDuplicates(tool.nombre):
                missing_tools.remove(tool.nombre)

        s0.off()
        s1.off()
        s2.off()
        s3.off()

    if missing_tools != [] and checkContacts():
        alarm.on()
    else:
        alarm.off()

    patchReq(f"cajas/{toolbox}", {"missing_tools": " | ".join(missing_tools), "state": True})

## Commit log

2022-04-22 docs: ordenar archivo readme (#1)
    * docs: agregar titulo de objetivo
    * docs: agregar titulo de funcionamiento
    * docs: agregar titulos informacion de contacto
2022-04-27 docs: agregar funcionamiento del proyecto (#2)
    * docs: añadir función de tareas
    * docs: añadir función principal del sistema
2022-06-08 feat: agregar interfaz grafica (#5)
    * feat: agregar interfaz grafica inicial
    * docs: agregar objetivo de la interfaz
    * chore: change favicon
    * chore: change typescript target to es6
2022-06-10 docs: arreglar el README (#6)
2022-06-12 docs: arreglar errores y cambiar logo de png a gif (#14)
    * docs: arreglar errores en README
    * docs: cambiar logo
    * docs: arreglar errores, cambiar logo de png a gif
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2022-06-14 docs: añadir datasheets (#15)
    * docs: añadir datasheet del esp32
    * docs: añadir pinout del esp32
    * docs: añadir datasheet del multiplexor
    * docs: añadir datasheet del lm7805
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2022-06-21 feat: agregar circuito KiCad (#18)
    [Circuito_ST_(completado).kicad_sch]
2022-06-24 docs: achicar letra integrantes (#23)
    * docs: achicar letra de integrantes
    * docs: achicar letra de integrantes
2022-07-01 feat: crear funcion de esperar señal de guardado (#27)
    * feat: añadir funcion de esperar guardado
    * refactor: separar url de la db en partes
2022-07-07 feat: añadir lista de herramientas (#28)
    * feat: agregar clase Herramientas y constructor
    * feat: crear un objeto por clase
    * feat: añadir advertencia
2022-07-07 feat: añadir pagina web inicial (#29)
    * feat: añadir pagina inicial
    * refactor: eliminar codigo de ejemplo
    * feat: usar bootstrap
    * feat: añadir el tag de Head
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2022-07-07 docs: arreglar errores de ortografia en readme (#31)
2022-07-08 feat: desarrollar listas (#32)
    * feat: agregar bootstrap
    * refactor: eliminar ExploreContainer
    * refactor: cambiar ruta de import
    * refactor: agrupar rutas en sus carpetas
    * feat: agregar UI de tareas
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2022-08-02 feat: agregar primera seccion pagina principal (#39)
    * feat: agregar favicon
    * feat: añadir @react-spring/parallax al proyecto
    * feat: añadir componente de header
    * feat: añadir video de fondo
    * feat: añadir imagen y titulo de header
    * feat: añadir el componente de ayuda para navegar
    * fix: arreglar layout del header
    * feat: añadir link de la pagina al readme
2022-08-04 feat: crear secciones pagina web (#40)
    * style: cambiar color de fondo
    * style: añadir componente a la pagina principal
    * feat: añadir filas y columnas de los botones
    * feat: añadir botones
2022-08-05 docs: añadir nuevo dominio pagina web (#42)
    * docs: reemplazar link en el titulo
    * docs: reemplazar link en la seccion de contactos
    * fix: arreglar seccion de contacto
    * fix: agregar redireccion a pagina web en contacto
2022-08-09 feat: agregar sección de redes (#43)
    * feat: crear componente de redes sociales
    * feat: añadir titulo de la seccion
    * feat: añadir iconos y sus respectivos links
    * feat: añadir estilos
    * chore: actualizar links
    * style: añadir mas estilos
2022-08-10 feat: leer tareas de la base de datos (#44)
    * feat: leer tareas de la base de datos
    * feat: hacer que se muestren las tareas correctamente
2022-08-16 feat: añadir quienes somos pagina web (#45)
    * fix: arreglar el diseño de la pagina en celulares
    * style: recortar logo
    * feat: añadir navbar
    * style: cambiar algunos estilos
    * feat: añadir paginas
    * feat: añadir tailwind a la pagina
    * feat: hacer diseño de navbar para moviles
    * feat: agregar logo impa
    * feat: desarrollar seccion de quienes somos
    * fix: arreglar un error en el mapa
    * fix: arreglar mapa en dispositivos moviles
2022-08-19 feat: actualizar circuito placa de control (#48)
    * refactor: borrar circuito descontinuado
    * feat: agregar circuito actualizado
    [Circuito_ST_(completado).kicad_sch, Placa_de_Control.kicad_sch]
2022-08-23 feat: añadir pagina de fotos (#49)
    * feat: crear carpeta de fotos
    * chore: cambiar nombre anterior de la pagina
    * feat: crear funcion que lea el directorio pictures
    * feat: añadir react-visibility-sensor
    * feat: agregar componente de galeria con imagenes
    * fix: solucionar error de estilos en el navbar
    * style: cambiar estilos de las imagenes
    * fix: arreglar un problema en el mapa
    * feat: agregar algunas imágenes
    * feat: cambiar el titulo de cada imagen
    * feat: agregar titulo de la pagina
2022-08-24 refactor: actualizar pinout esp32 (#50)
    * refactor: remover datasheet desactualizado
    * feat: añadir pinout esp32 actualizado
2022-08-28 feat: continuar codigo microcontrolador (#52)
    * feat: añadir I/O de los contactos magneticos
    * feat: empezar el codigo que verifica los contactos
    * chore: cambiar pines
    * chore: modificar constructor
    * feat: añadir indentificacion de herramientas
    * feat: añadir seleccion de contacto magnetico
    * chore: usar un contacto por el momento
    * feat: encender la linea de cada herramienta
    * feat: agregar puertos del multiplexor
    * feat: comprobar si una herramienta está
    * chore: agregar numero de caja
    * chore: agregar el atributo de nombre
    * feat: hacer un patch al detectar cambios
    * fix: cambiar el estado a false
    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
2022-08-28 feat: desarrollar pagina de circuitos y planos (#51)
    * feat: añadir foto de circuito
    * feat: agregar titulo
    * feat: terminar pagina de circuitos
    * feat: añadir componentes externos
2022-09-01 feat: hacer cambios en pagina web (#54)
    * chore: cambiar a typescript
    * chore: cambiar nombre y apellido de lugar
    * feat: agregar cuentas de instagram
    * feat: agregar icono de instagram en contacto
    * feat: agregar fotos a la galeria
    * fix: reemplazar los numeros de los archivos
    * feat: agregar perspectiva de planos
    * feat: cambiar paleta de colores
    * fix: cambiar velocidad de los botones en index
    * fix: arreglar problemas entre typescript y css
2022-09-08 feat: actualizar codigo android (#55)
    * fix: mostrar QR en la aplicación
    * feat: actualizar codigo de android
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2022-09-09 docs: actualizar readme (#57)
    * docs: actualizar seccion de contacto
    * fix: arreglar tamaño de subtitulos
    * fix: cambiar la seccion de integrantes
    * docs: añadir tecnologías utilizadas
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2022-09-15 feat: crear seccion funcionamiento (#59)
    * fix: arreglar css en la pagina de circuitos
    * feat: añadir seccion de objetivo y funcionamiento
    * feat: añadir diagrama de flujo
    * feat: añadir seccion de funcionamiento de aplicacion movil
    * feat: añadir seccion de funcionamiento de interfaz grafica
    * feat: añadir seccion de funcionamiento de la caja
    * fix: arreglar errores en margenes
2022-09-16 feat: implementar señal guardado interfaz grafica (#61)
    * refactor: borrar dependencias sin usar
    * refactor: cambiar favicon
    * feat: añadir bootstrap
    * feat: añadir firebase al proyecto
    * feat: crear rutas de la app
    * feat: crear pagina de inicio
    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
2022-09-17 feat: desarrollar página de agregar tareas (#62)
    * feat: crear componente de Tareas
    * feat: mostrar operario seleccionado de la db
    * feat: mostrar las tareas de cada operario
    * feat: añadir bloque de input para añdir tareas
    * feat: agregar funcionalidad de agregar y eliminar
2022-09-19 feat: actualizar esquematico placa de control (#63)
    * refactor: borrar esquematico descontinuado
    * feat: agregar esquematico actualizado
    [Placa _de_Control.kicad_sch]
2022-09-19 feat: enviar qr base de datos (#64)
    * feat: enviar datos con update
    * fix: arreglar tipos de typescript
2022-09-22 feat: agregar fotos (#66)
    * feat: agregar mas fotos
    * chore: cambiar foto de inicio
    * refactor: cambiar estilos en funcionamiento
    * chore: cambiar foto de funcionamiento
    * fix: arreglar titulo en moviles
    * chore: cambiar foto de circuitos
    * chore: cambiar scrollbar
2022-09-22 feat: agregar registro usuario (#65)
    * feat: agregar boton de usuario
    * feat: agregar boton de login
    * feat: agregar contexto de usuario
    * chore: hacer cambios menores
    * style: cambiar estilos de la app
    * feat: cambiar las tareas dependiendo del usuario
    * feat: aplicacion terminada
    * chore: cambiar nombre de la app
    * refactor: reorganizar codigo
    * fix: arreglar declaracion de modulos
    * feat: agregar iconos
    * chore: cambiar nombre de la app
    * style: arreglar problemas de UI
2022-09-23 feat: implementar seccion cajas interfaz (#68)
    * chore: agregar elemento a la ruta cajas
    * feat: agregar tabla
    * feat: agregar columnas
    * feat: crear columna de cajas
    * feat: crear columna de estado de caja
    * feat: crear columna de herramientas faltantes
    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
2022-09-23 feat: pasar interfaz grafica aplicacion escritorio (#69)
    * feat: agregar electron al proyecto
    * chore: cambiar de browserrouter a hashrouter
    * chore: cambiar URL en produccion
    * feat: agregar comandos a los archivos package
    * chore: agregar autor
    * chore: dist a gitignore
    * fix: arreglar rutas de imagen para electron
    * feat: agregar aplicacion de escritorio
2022-09-23 docs: ordenar repositorio (#70)
    * refactor: reordenar README
    * refactor: eliminar datasheet del cny70
    * refactor: eliminar datasheet del LM7805
    * docs: añadir descripción de la aplicación móvil
    * docs: agregar descripción de la interfaz gráfica
    * docs: agregar descripción del microcontrolador
    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
2022-09-24 fix: ultimos arreglos pagina web (#71)
    * fix: arreglar errores gramaticales
    * chore: cambiar cards en nosotros
    * fix: cambiar materiales utilizados
    * fix: arreglar tamaño del logo nuevo
    * feat: agregar linkedin personales
    * chore: cambiar flecha dependiendo del dispositivo
    * fix: arreglar error en useEffect
    * feat: agregar instagram del proyecto
2022-09-24 Docs: arreglar errores de tipeo (#72)
    * docs: arreglar error de tipeo en readme
    * docs: arreglar error de redaccion en readme
2022-09-30 feat: crear primer prototipo de codigo de uC (#73)
    * feat: crear programa de testeo de uC
    * feat: agregar programa hardcodeado de deteccion
    * refactor: cambiar a OOP
    * feat: agregar alarma
    * refactor: eliminar codigo innecesario
    * docs: agregar comentarios
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2022-10-04 chore: actualizar pagina web (#76)
    * feat: agregar link a SpaceApps
    * fix: ajustar tamaño de las cards
    * chore: cambiar pagina de circuitos
    * feat: añadir mas fotos
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2022-10-05 feat: agregar la opción de añadir usuarios y cajas (#78)
    * refactor: organizar componentes en carpetas
    * fix: actualizar imports
    * feat: agregar modal de cajas
    * feat: agregar modal de usuarios
    * feat: agregar aplicacion de escritorio version 2
2022-10-11 feat: agregar circuito impreso e imagenes (#81)
    [circuito_impreso.kicad_pcb]
2022-10-11 feat: finalizar esquematico placa de control (#80)
    * refactor: borrar esquematico desactualizado
    * refactor: borrar esquematico desactualizado
    * feat: agregar circuito finalizado e imagenes
    [placa_de_control.kicad_sch]
2022-10-17 feat: preparar proyecto para oniet (#83)
    * feat: alerta si no está registrado
    * feat: esconder herramientas vacías
    * fix: invertir lógica de detección
    * feat: agregar apk
    * feat: borrar input despues de enviar
    * style: cambiar estilos
    [primer_prototipo.py]
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
